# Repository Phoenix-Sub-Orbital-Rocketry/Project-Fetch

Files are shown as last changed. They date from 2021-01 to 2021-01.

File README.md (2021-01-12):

# Project-Fetch

# About Fetch
Fetch is a symmetrical point to point tracking system Phoenix Sub-Orbital Rocketry developed using the 915Mhz LoRa frequency and protocol. As well as being symmetrical, the system is completely self-contained with an onboard LiPo battery, OLED screen and signal processing capabilities. Fetch works based on a unique "Hot, Cold" tracking system spcially developed by Phoenix Sub-Orbital Rocketry which allows for many features such as complete, inertial tracking, aka no need for GPS! Fetch was orgininally designed as a part of a larger Flight Computer system for High Powered, Sub-Orbital Rockets before being spun off into it's own system after it's creator realized it's potential as a stand alone system.  For more information, read the file and user manual.

# How to Use the Files in This Repository
The creator of Project Fetch has decided to make all of the files nessisary for it's creation, open source and free in this repository. The files in this repository include the Gerber files and BOM for the main PCB, The STL file for the case, the ardunio code for the entire system and the assembly and use instructions. Also inluded is the STL flies and assembly instructions for a 4 node, 3D printable Yagi antenna that is still in development but may become a part of the standard Fetch kit.

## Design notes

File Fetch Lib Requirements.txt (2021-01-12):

In order to compile and upload the software to Fetch, you need these libraries:

	SPI.h
	Wire.h
	LoRa.h
	Adafruit_GFX.h
	Adafruit_SSD1306.h

All of these libraries can be found through the library manager in the Arduino IDE and/or Github

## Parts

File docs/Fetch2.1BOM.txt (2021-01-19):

Object                                                                           |     Quanity
                                                                                 |         
Adafruit ItsyBitsy M0 Express - for CircuitPython & Arduino IDERFM95W Module     |        2
SMA Female Jack Connector, Brass PCB Clip Edge Mount Adapter                     |        2
2mm Pitch 40-Pin Break-apart Male Headers                                        |        1
Lithium Ion Polymer Battery - 3.7v 350mAh                                        |        2
Adafruit LiIon/LiPoly Backpack Add-On for Pro Trinket/ItsyBitsy                  |        2
0.91 Inch I2C SSD1306 OLED Display Module                                        |        2

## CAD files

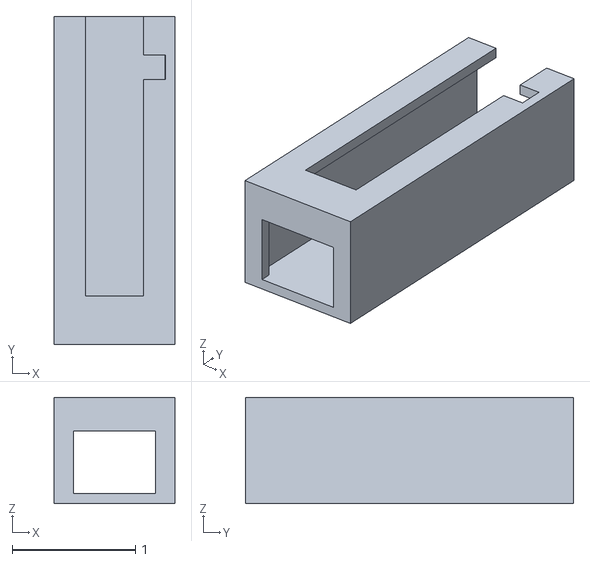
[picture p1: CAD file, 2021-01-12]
hardware/3D-Print/Fetchcase V2.stl
0.98 x 2.66 x 0.86

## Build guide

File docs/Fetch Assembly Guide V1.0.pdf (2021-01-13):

By Christopher Texler

1

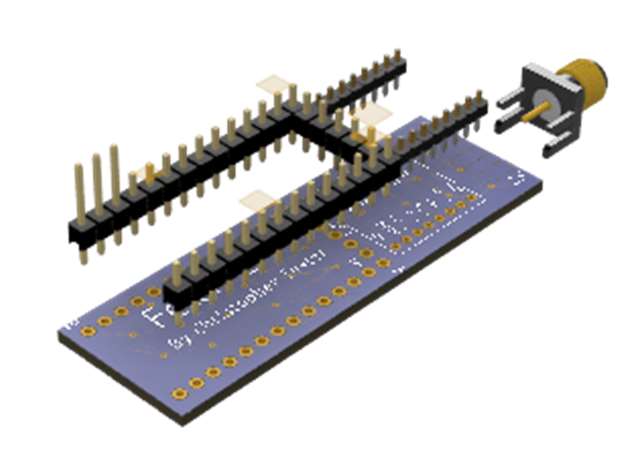
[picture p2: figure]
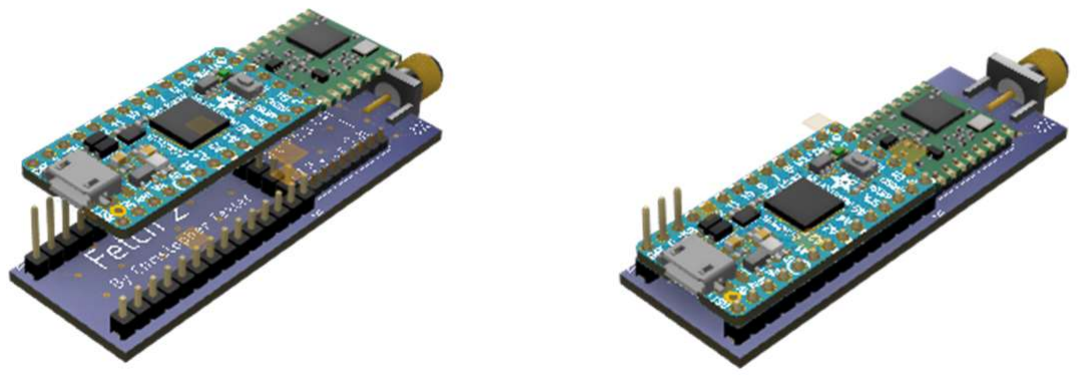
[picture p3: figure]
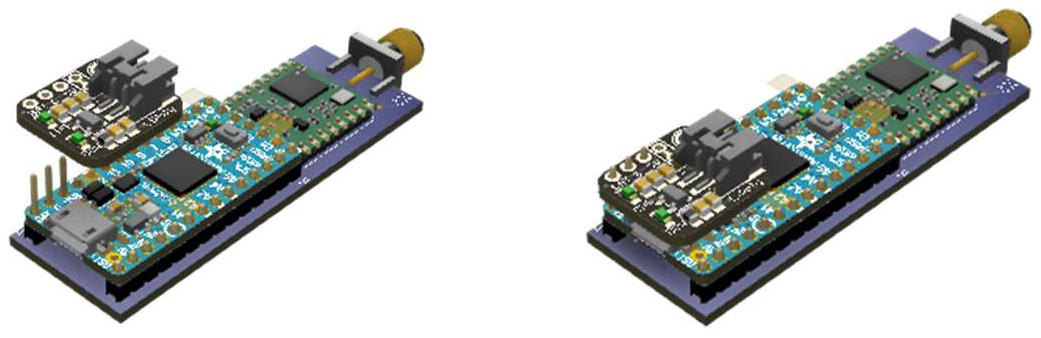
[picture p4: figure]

Copyright Pending ©2021

# Fetch Assembly guide Ver 1.0

## Hardware Assembly

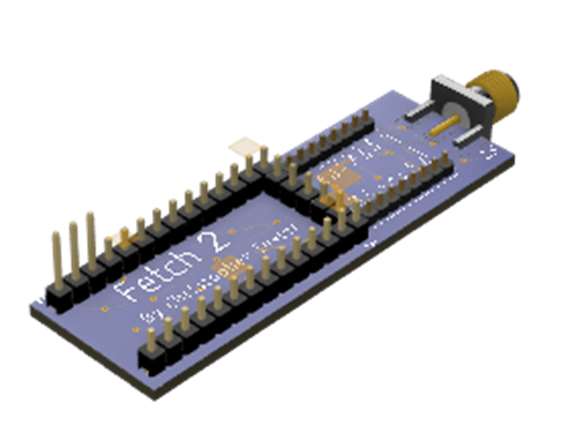
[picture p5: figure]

Step 1:
Insert and solder the pin headers and SMD board connector onto the main board as shown in the pictures to the left of this caption.
Step 2:
Insert the Itsy bitsy M0 and RFM 95W boards onto the pins and solder them in place as shown in the pictures to the left of this caption.
Step 3:
Insert the Adafruit battery charging backpack board onto the

### 3 tall pins sticking through the itsy-

bitsy board and solder it in place as shown in the pictures to the left of this caption.

2

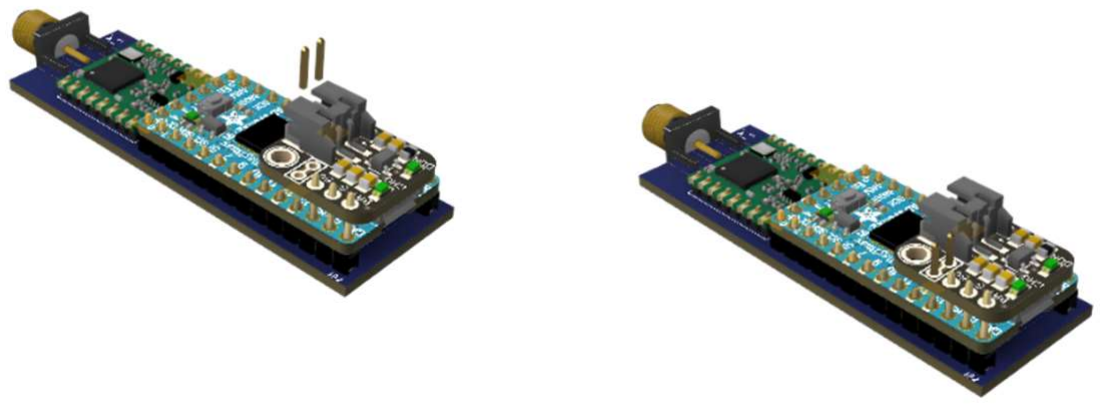
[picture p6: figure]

Step 4:
Insert two pins cut from a pin header into the battery output pin holes after carefully cutting the trace between them and solder them in place as shown in the pictures to the left of this caption.

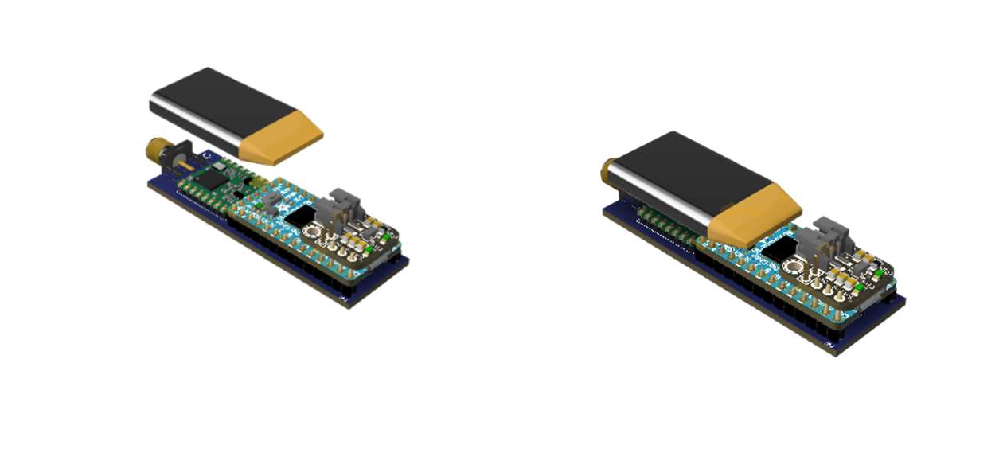
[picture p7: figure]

Step 5:
Put some masking tape on the side of the battery that will be facing the board and set it on top of the assembly while connecting it to the battery charging backpack as shown in the pictures to the left of this caption.

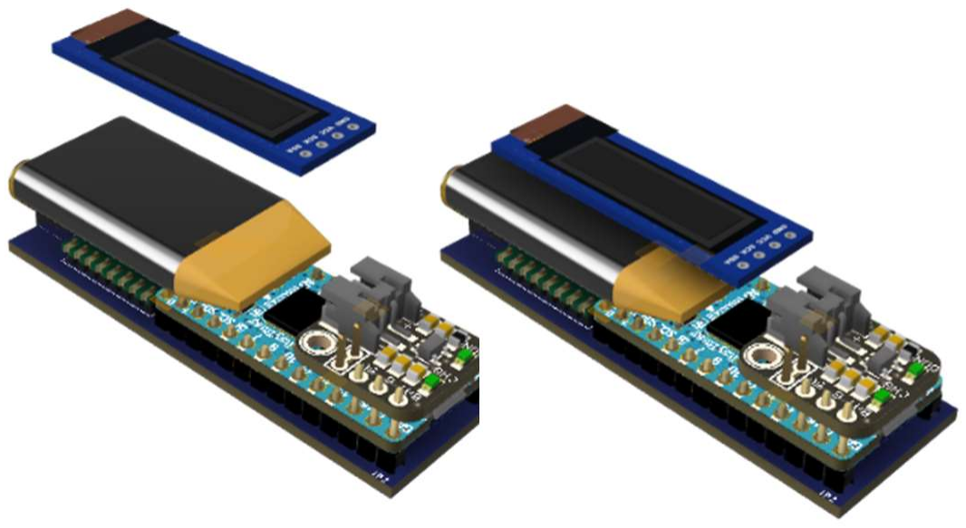
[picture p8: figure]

Step 6:
Place the OLED screen on top of the battery and connect it to the corresponding pins on the Itsy bitsy via jumper wires and solder joints as shown in the pictures to the left of this caption. (Note, make sure to route everything to be as
compact as possible, this may mean custom cutting and
stripping jumper wires)

3

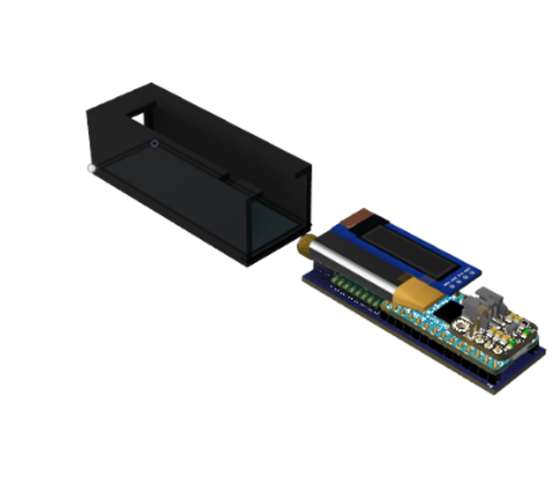
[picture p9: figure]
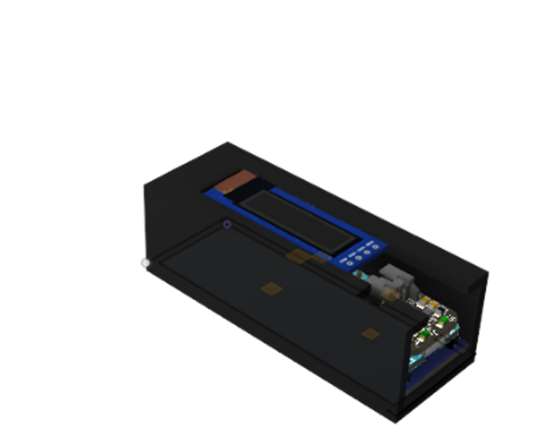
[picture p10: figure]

Step 7:
Slip the 3d printed case over the entire assembly, making sure to align the OLED to the large channel and line up the ON/Off jumper pins to the
smaller channel as shown in the pictures to the left of this caption.
Step 8:
Insert the corresponding antenna onto the SMA connector as shown in the pictures to the left of this caption.

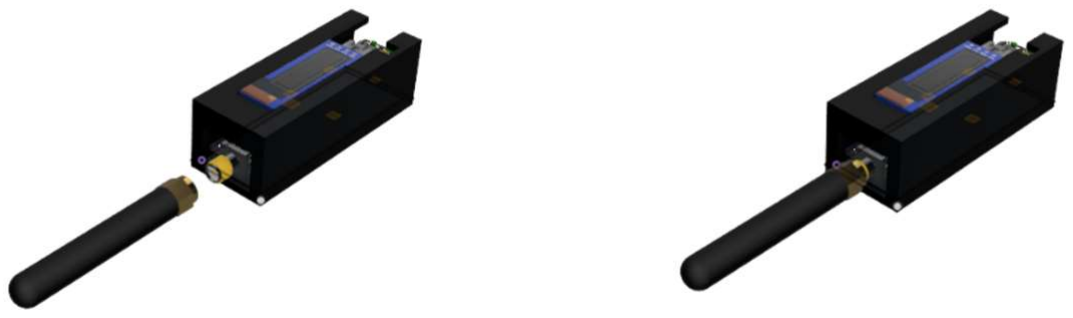
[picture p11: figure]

Congratulations! You’ve completed one Fetch Box! Now you get to make another! The Hardware for Fetch is identical for the transmitter as it is for the Fetch Ground Station, with the exception of the antenna. This means that to make the hardware for a full Fetch system, you just need to make 2 Fetch boxes and equip one with an omni directional antenna and one with a directional antenna.

## Software Integration

Thankfully, when hardware assembly is done correctly, software integration is easy to do. First, put the itsy bitsy into Arduino programing mode via the tutorial available at Adafruit. Then, upload the proper sketch to each box based on its purpose, ie the GS script should be uploaded to the box that will serve as the ground station and the payload script to the box that will serve as that transmitter. Some warnings before doing any of this, though, never power the system without the antenna or else it might damage the RFM module. Also, when putting the itsy bitsy into programing mode, use a plastic instrument, not a metal one.

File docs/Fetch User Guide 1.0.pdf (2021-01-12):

Phoenix Sub-Orbital Rocketry

# Fetch User’s Guide

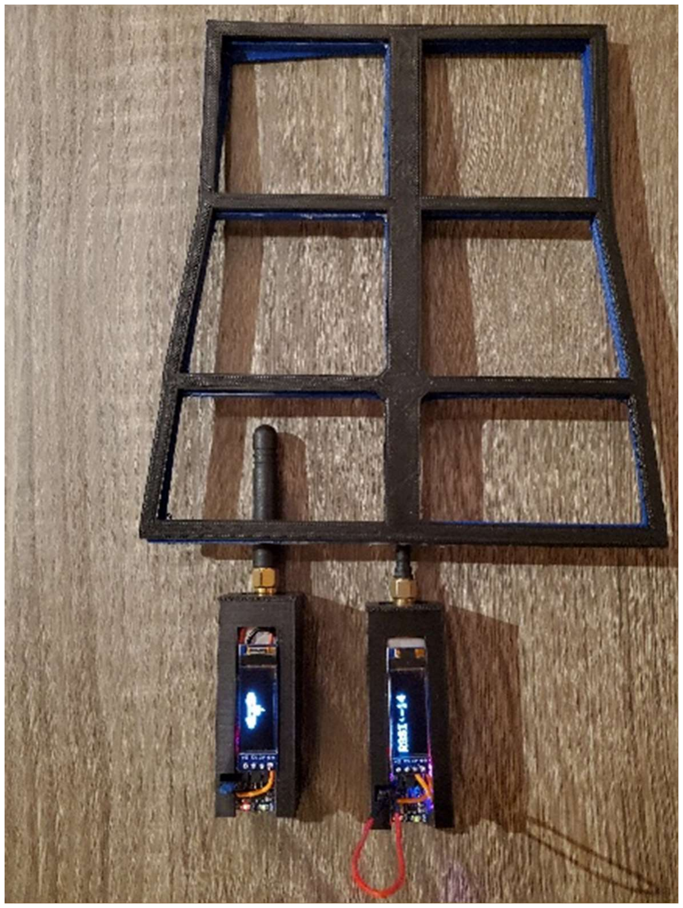
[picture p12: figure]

Ver 1.0

### Christopher Texler

1-12-2021

1

## Table of Contents:

Hardware Map:
Basic Usage:
The Math Behind the Magic:

## Hardware Map:

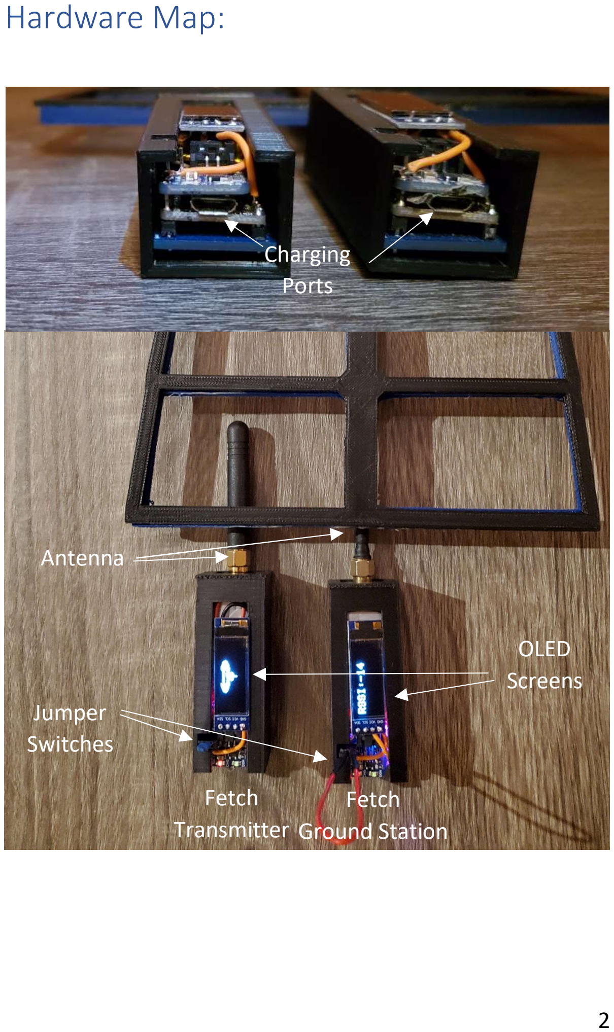
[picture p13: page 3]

2

Fetch
Transmitter

Fetch
Ground Station

Jumper
Switches

OLED
Screens

Antenna

Charging
Ports

3

## Basic Usage:

Turning the System on:
To turn the transmitter and ground station on, simply plug the jumper wires into the two prongs sticking out of the cut-out area in the case as seen in the hardware map.
Reading and Operating the Ground Station:
When the ground station and transmitter initially turn on, they will display a slash screen of the Phoenix Sub-Orbital Rocketry logo before displaying RSSI:(some number). The number on the transmitter can be ignored as the RSSI: screen on the transmitter is nonfunctional and only to be used as a power indicator. However, the RSSI: screen on the ground station is functional and is the number to read for tracking. The way to read the number is that less negative the closer and stronger of a signal you have. This means that when a directional antenna is connected to the ground station, you can tell when you’re facing towards the transmitter via the number going closer to zero than when facing other directions.

4

## The Math Behind the Magic:

Fetch works on an incredibly simple, yet ingenious concept, the transmitter sends out 915MHz “Pings” every ~0.5 seconds, the ground station receives those “pings” and then it displays the signal integrity in RSSI on the screen.
The secret behind how Fetch can use just the “pings” coming from the transmitter to track it can be boiled down to two major principles, the antenna and the signal processing capability of the human brain.
The Antenna:
First off is the black magic that is directional antenna design. For the Fetch system to work properly, the user needs to connect a directional antenna to the ground station. This is because otherwise, with an omni directional antenna, it’d show the same RSSI no matter the direction relative to the transmitter. The directional antenna works by using passive elements of wire to “reflect” and directionalize the signal and have a better signal in one direction than the other which allows it to receive a signal very well in one direction, and all but cut off in any other direction.
How to Turn Signal Strength into Directions
Since the ground station only outputs the signal integrity number, it’s up to the operator to translate that number into a direction. This is by design, though, as humans happen to be really good at playing the “Hot, Cold” game of narrowing down results which is exactly how to best operate and think about Fetch.

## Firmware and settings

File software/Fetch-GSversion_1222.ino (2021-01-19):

/**************************************************************************
This is the current GUI code for the Fetch Tracking system

Written by Christopher Texler
 **************************************************************************/

#include <SPI.h>
#include <Wire.h>
#include <LoRa.h>
#include <Adafruit_GFX.h>
#include <Adafruit_SSD1306.h>

#define SCREEN_WIDTH 128 // OLED display width, in pixels
#define SCREEN_HEIGHT 32 // OLED display height, in pixels

// Declaration for an SSD1306 display connected to I2C (SDA, SCL pins)
#define OLED_RESET     4 // Reset pin # (or -1 if sharing Arduino reset pin)
Adafruit_SSD1306 display(SCREEN_WIDTH, SCREEN_HEIGHT, &Wire, OLED_RESET);

int RSSi; 	// declare global


#define LOGO_HEIGHT   32
#define LOGO_WIDTH    64
static const unsigned char PROGMEM logo_bmp[] =
{ 0x00, 0x00, 0x00, 0x00, 0x00, 0x00, 0x00, 0x00, 0x00, 0x0f, 0xc0, 0x00, 0x00, 0x0f, 0xc0, 0x00, 
  0x00, 0x7f, 0x00, 0x00, 0x00, 0x1f, 0xf8, 0x00, 0x00, 0x7c, 0x00, 0x00, 0x00, 0x7c, 0xf9, 0x00, 
  0x0e, 0xfc, 0x3f, 0xff, 0xff, 0xfc, 0xfd, 0xc0, 0x1f, 0x7f, 0xff, 0xff, 0xff, 0xfe, 0xfb, 0xe0, 
  0x3f, 0xfc, 0xff, 0xff, 0xff, 0xfc, 0xff, 0xf0, 0x3f, 0xfe, 0x00, 0x00, 0x00, 0xfd, 0xff, 0xf0, 
  0x5f, 0xfc, 0x00, 0x00, 0x00, 0x3c, 0xff, 0xf8, 0x7f, 0xfd, 0x00, 0x00, 0x00, 0x0a, 0xff, 0xf8, 
  0x7f, 0xfd, 0x80, 0x00, 0x18, 0x06, 0xff, 0xf8, 0x3f, 0xfe, 0xe0, 0x07, 0xf0, 0x1f, 0xff, 0xf0, 
  0x1f, 0xff, 0xff, 0x3f, 0xe3, 0xff, 0xff, 0xe0, 0x07, 0xcf, 0xff, 0x8f, 0xe7, 0xff, 0xcf, 0x00, 
  0x01, 0xff, 0xff, 0xcf, 0xef, 0xff, 0xfe, 0x00, 0x00, 0x3f, 0xff, 0xff, 0xff, 0xff, 0xf0, 0x00, 
  0x00, 0x03, 0xfb, 0xff, 0xff, 0x7f, 0x00, 0x00, 0x00, 0x00, 0x00, 0x1f, 0xe0, 0x00, 0x00, 0x00, 
  0x00, 0x00, 0x00, 0x3f, 0xf0, 0x00, 0x00, 0x00, 0x00, 0x00, 0x00, 0xff, 0xfc, 0x00, 0x00, 0x00, 
  0x00, 0x00, 0x01, 0xff, 0xfe, 0x00, 0x00, 0x00, 0x00, 0x00, 0x01, 0x7f, 0xfa, 0x00, 0x00, 0x00, 
  0x00, 0x00, 0x00, 0xff, 0xfc, 0x00, 0x00, 0x00, 0x00, 0x00, 0x00, 0xfb, 0xbc, 0x00, 0x00, 0x00, 
  0x00, 0x00, 0x00, 0x1b, 0x30, 0x00, 0x00, 0x00, 0x00, 0x00, 0x00, 0x03, 0x20, 0x00, 0x00, 0x00, 
  0x00, 0x00, 0x00, 0x01, 0x00, 0x00, 0x00, 0x00, 0x00, 0x00, 0x00, 0x01, 0x00, 0x00, 0x00, 0x00,
  0x00, 0x00, 0x00, 0x01, 0x00, 0x00, 0x00, 0x00, 0x00, 0x00, 0x00, 0x01, 0x00, 0x00, 0x00, 0x00,
  0x00, 0x00, 0x00, 0x01, 0x00, 0x00, 0x00, 0x00, 0x00, 0x00, 0x00, 0x01, 0x00, 0x00, 0x00, 0x00,};

void setup() {

   // SSD1306_SWITCHCAPVCC = generate display voltage from 3.3V internally
  if(!display.begin(SSD1306_SWITCHCAPVCC, 0x3C)) { // Address 0x3C for 128x32
    Serial.println(F("SSD1306 allocation failed"));
    for(;;); // Don't proceed, loop forever
  }
    // Clear the buffer
  display.clearDisplay();
  Serial.begin(9600);
  

  Serial.println("LoRa Receiver");

  if (!LoRa.begin(915E6)) {
    Serial.println("Starting LoRa failed!");
    while (1);
  }


  drawlogo();    // Draw a splashscreen of the Old Phoenix Sub-Orbital Logo

}

void loop() {
      // try to parse packet
    int packetSize = LoRa.parsePacket();
    if (packetSize) {
      // received a packet
      Serial.print("Received packet '");

      // read packet
      while (LoRa.available()) {
        Serial.print((char)LoRa.read());
        // read the RSSI, push out serial port for debug and display on OLED
        RSSi = LoRa.packetRssi();
      }
      // print RSSI of packet
      Serial.print("' with RSSI ");
      Serial.println(RSSi);

  }

      drawRSSI();    // Draw the current RSSI value based on a varbile set earlier in the code
      delay(100);
      display.clearDisplay();
      display.display();
}


void drawRSSI(void) {
  display.clearDisplay();
  
  display.setTextSize(2);             // Draw 3X-scale text
  display.setTextColor(SSD1306_WHITE);
  display.setCursor(0,0);             // Start at top-left corner
  display.print("RSSI:");
  display.println(RSSi);

  display.display();
  delay(100);
}



void drawlogo(void) {
  display.clearDisplay();

  display.drawBitmap(
    (display.width()  - LOGO_WIDTH ) / 2,
    (display.height() - LOGO_HEIGHT) / 2,
    logo_bmp, LOGO_WIDTH, LOGO_HEIGHT, 1);
  display.display();
  delay(3000);
}
